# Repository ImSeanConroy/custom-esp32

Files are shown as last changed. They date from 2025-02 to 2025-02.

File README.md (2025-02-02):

# Custom ESP32

Complete design files for an ESP32 microcontroller-based board, created using KiCad

## License

This project is Distributed under the MIT License - see the [LICENSE](LICENSE) file for information.

## Support

If you are having problems, please let me know by [raising a new issue](https://github.com/ImSeanConroy/custom-esp32/issues/new/choose).

## Acknowledgments

A special thanks to the creators of these invaluable resources that helped guide this project:

- [How to Design a Custom ESP32 PCB](https://thehardwareacademy.com/courses/how-to-design-esp32-pcb/): Learn how to design a custom PCB using the Espressif ESP32-S3 WiFi/Bluetooth wireless microcontroller module.

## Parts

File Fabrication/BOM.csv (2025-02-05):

Designator | Qty | JLPCB Part # | Value | Footprint
U3 | 1 | ESP32-S3-MINI-1-N8 | - | ESP32-S3-MINI-1-N8:XCVR_ESP32-S3-MINI-1-N8
U1 | 1 | ESD7104MUTAG | - | Package_DFN_QFN:Diodes_UDFN-10_1.0x2.5mm_P0.5mm
U4 | 1 | TLV75801PDRVR | - | Package_SON:WSON-6-1EP_2x2mm_P0.65mm_EP1x1.6mm
U2 | 1 | ENS210-LQFM | - | Package_DFN_QFN:AMS_QFN-4-1EP_2x2mm_P0.95mm_EP0.7x1.6mm
BOOT1, RESET1 | 2 | PTS810 SJK 250 SMTR LFS | - | Button_Switch_SMD:SW_SPST_PTS810
J3 | 1 | USB4105-GF-A | - | Connector_USB:USB_C_Receptacle_GCT_USB4105-xx-A_16P_TopMnt_Horizontal
D1 | 1 | COM-16347 | - | LED_SMD:LED_WS2812B_PLCC4_5.0x5.0mm_P3.2mm
D2 | 1 | 150060RS75000 | - | LED_SMD:LED_0603_1608Metric
J1, J2 | 2 | 61302211121 | - | Connector_PinHeader_2.54mm:PinHeader_1x22_P2.54mm_Vertical
C1, C2, C3, C5 | 4 | CC0603KRX7R7BB104 | 0.1uF | Capacitor_SMD:C_0603_1608Metric
C4, C6, C7 | 3 | CL10A106MQ8NNNC | 10uF | Capacitor_SMD:C_0603_1608Metric
R1, R2, R8 | 3 | RC0603FR-075K1L | 5.1k | Resistor_SMD:R_0603_1608Metric
R3, R4, R5 | 3 | RC0603FR-0710KL | 10k | Resistor_SMD:R_0603_1608Metric
R6 | 1 | RT0603BRD071ML | 1M | Resistor_SMD:R_0603_1608Metric
R7 | 1 | RC0603FR-07200KL | 200k | Resistor_SMD:R_0603_1608Metric

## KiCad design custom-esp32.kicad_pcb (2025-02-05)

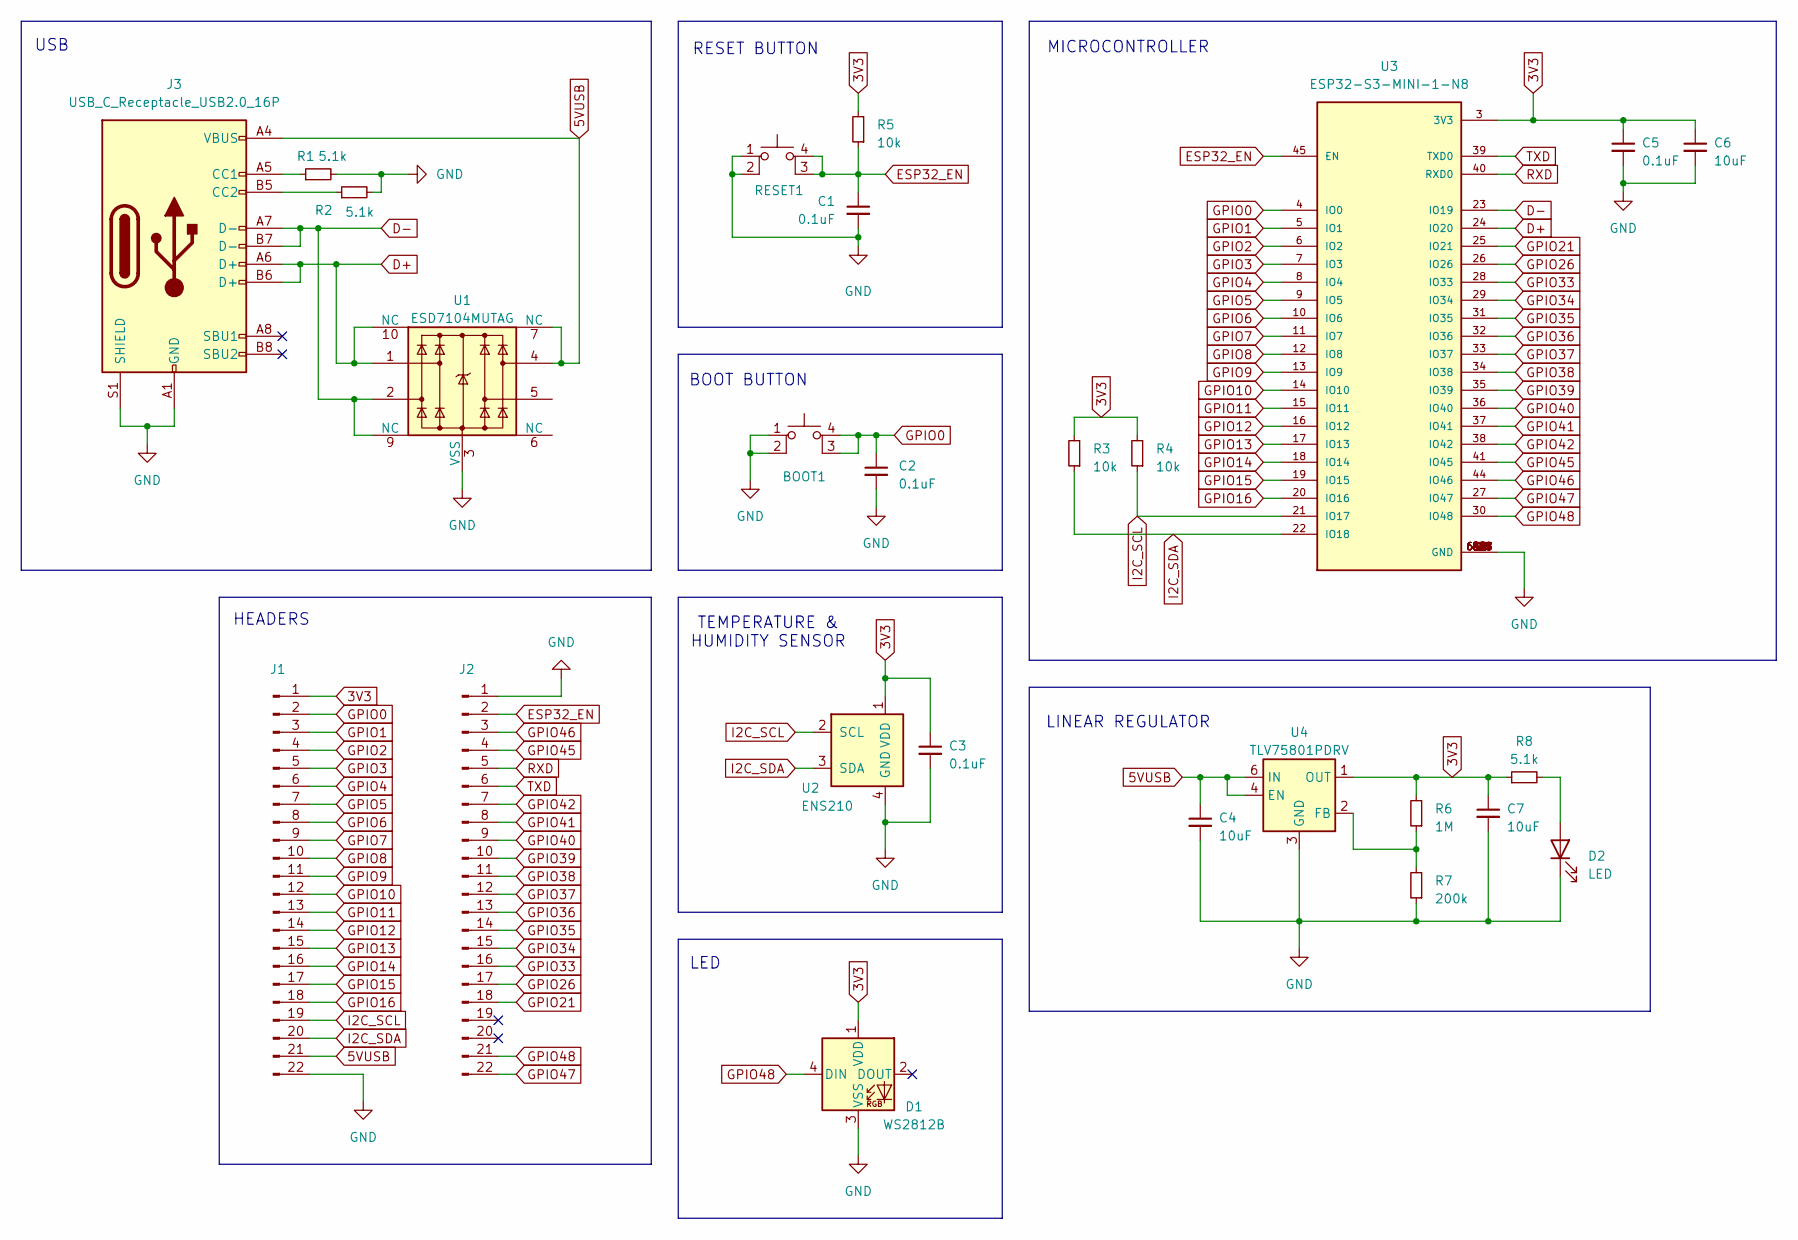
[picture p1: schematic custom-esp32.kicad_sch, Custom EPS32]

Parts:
BOOT1: SW_SPST_PTS810
C1, C2, C3, C5: 0.1uF; C_0603_1608Metric
C4, C6, C7: 10uF; C_0603_1608Metric
D1: WS2812B; LED_WS2812B_PLCC4_5.0x5.0mm_P3.2mm
D2: LED; LED_0603_1608Metric
J1, J2: PinHeader_1x22_P2.54mm_Vertical
J3: USB_C_Receptacle_USB2.0_16P; USB_C_Receptacle_GCT_USB4105-xx-A_16P_TopMnt_Horizontal
R1, R2, R8: 5.1k; R_0603_1608Metric
R3, R4, R5: 10k; R_0603_1608Metric
R6: 1M; R_0603_1608Metric
R7: 200k; R_0603_1608Metric
RESET1: SW_SPST_PTS810
U1: ESD7104MUTAG; Diodes_UDFN-10_1.0x2.5mm_P0.5mm
U2: ENS210; AMS_QFN-4-1EP_2x2mm_P0.95mm_EP0.7x1.6mm
U3: ESP32-S3-MINI-1-N8; XCVR_ESP32-S3-MINI-1-N8; PARTREV v0.6
U4: TLV75801PDRV; WSON-6-1EP_2x2mm_P0.65mm_EP1x1.6mm

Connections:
3V3: C3.1, C5.1, C6.1, C7.1, D1.1 (VDD), J1.1, R3.2, R4.2, R5.2, R6.2, R8.1, U2.1 (VDD), U3.3 (3V3), U4.1 (OUT)
5VUSB: C4.1, J1.21, J3.A4 (VBUS), J3.A9 (VBUS), J3.B4 (VBUS), J3.B9 (VBUS), U1.4, U1.7 (NC), U4.4 (EN), U4.6 (IN)
D+: J3.A6 (D+), J3.B6 (D+), U1.1, U1.10 (NC), U3.24 (IO20)
D-: J3.A7 (D-), J3.B7 (D-), U1.2, U1.9 (NC), U3.23 (IO19)
ESP32_EN: C1.1, J2.2, R5.1, RESET1.3 (K), RESET1.4 (A), U3.45 (EN)
GND: BOOT1.1, BOOT1.2, C1.2, C2.2, C3.2, C4.2, C5.2, C6.2, C7.2, D1.3 (VSS), D2.1 (K), J1.22, J2.1, J3.A1 (GND), J3.A12 (GND), J3.B1 (GND), J3.B12 (GND), J3.S1 (SHIELD), R1.2, R2.2, R7.1, RESET1.1, RESET1.2, U1.3 (VSS), U1.8 (VSS), U2.4 (GND), U2.5 (GND), U3.1 (GND), U3.2 (GND), U3.42 (GND), U3.43 (GND), U3.46 (GND), U3.47 (GND), U3.48 (GND), U3.49 (GND), U3.50 (GND), U3.51 (GND), U3.52 (GND), U3.53 (GND), U3.54 (GND), U3.55 (GND), U3.56 (GND), U3.57 (GND), U3.58 (GND), U3.59 (GND), U3.60 (GND), U3.61 (GND), U3.61_1 (GND), U3.61_2 (GND), U3.61_3 (GND), U3.61_4 (GND), U3.61_5 (GND), U3.61_6 (GND), U3.61_7 (GND), U3.61_8 (GND), U3.62 (GND), U3.63 (GND), U3.64 (GND), U3.65 (GND), U4.3 (GND), U4.7 (GND)
GPIO0: BOOT1.3 (K), BOOT1.4 (A), C2.1, J1.2, U3.4 (IO0)
GPIO1: J1.3, U3.5 (IO1)
GPIO2: J1.4, U3.6 (IO2)
GPIO3: J1.5, U3.7 (IO3)
GPIO4: J1.6, U3.8 (IO4)
GPIO5: J1.7, U3.9 (IO5)
GPIO6: J1.8, U3.10 (IO6)
GPIO7: J1.9, U3.11 (IO7)
GPIO8: J1.10, U3.12 (IO8)
GPIO9: J1.11, U3.13 (IO9)
GPIO10: J1.12, U3.14 (IO10)
GPIO11: J1.13, U3.15 (IO11)
GPIO12: J1.14, U3.16 (IO12)
GPIO13: J1.15, U3.17 (IO13)
GPIO14: J1.16, U3.18 (IO14)
GPIO15: J1.17, U3.19 (IO15)
GPIO16: J1.18, U3.20 (IO16)
GPIO21: J2.18, U3.25 (IO21)
GPIO26: J2.17, U3.26 (IO26)
GPIO33: J2.16, U3.28 (IO33)
GPIO34: J2.15, U3.29 (IO34)
GPIO35: J2.14, U3.31 (IO35)
GPIO36: J2.13, U3.32 (IO36)
GPIO37: J2.12, U3.33 (IO37)
GPIO38: J2.11, U3.34 (IO38)
GPIO39: J2.10, U3.35 (IO39)
GPIO40: J2.9, U3.36 (IO40)
GPIO41: J2.8, U3.37 (IO41)
GPIO42: J2.7, U3.38 (IO42)
GPIO45: J2.4, U3.41 (IO45)
GPIO46: J2.3, U3.44 (IO46)
GPIO47: J2.22, U3.27 (IO47)
GPIO48: D1.4 (DIN), J2.21, U3.30 (IO48)
I2C_SCL: J1.19, R4.1, U2.2 (SCL), U3.21 (IO17)
I2C_SDA: J1.20, R3.1, U2.3 (SDA), U3.22 (IO18)
unnamed: D2.2 (A), R8.2
unnamed: J3.A5 (CC1), R1.1
unnamed: J3.B5 (CC2), R2.1
unnamed: R6.1, R7.2, U4.2 (FB)
RXD: J2.5, U3.40 (RXD0)
TXD: J2.6, U3.39 (TXD0)

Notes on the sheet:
RESET BUTTON
MICROCONTROLLER
LINEAR REGULATOR
LED
BOOT BUTTON
TEMPERATURE & HUMIDITY SENSOR
HEADERS
USB

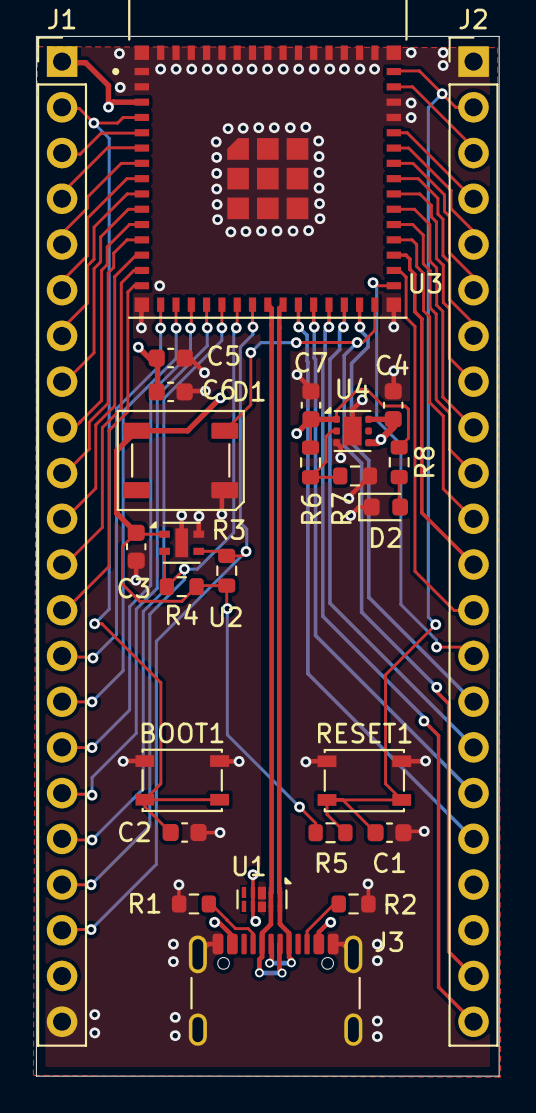
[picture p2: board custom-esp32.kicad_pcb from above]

Board: 4 copper layers, 25.7 x 57.8 mm, 26 parts (0 on the bottom side), 47 nets.

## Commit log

2024-11-16 Setup kicad project
    [custom-esp32.kicad_pcb, custom-esp32.kicad_sch]
2024-11-16 Create schematic
    [custom-esp32.kicad_sch]
2025-02-02 Update schematic
    [custom-esp32.kicad_pcb, custom-esp32.kicad_sch]
2025-02-03 Add initial pcb layout
    [custom-esp32.kicad_pcb]
2025-02-04 Connect remaining components in pcb layout
    [custom-esp32.kicad_pcb]
2025-02-05 Add missing 3d models and resolve design issues
    [custom-esp32.kicad_pcb]
2025-02-05 Add fabrication files
    [BOM.csv, Component-Placement.csv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]
